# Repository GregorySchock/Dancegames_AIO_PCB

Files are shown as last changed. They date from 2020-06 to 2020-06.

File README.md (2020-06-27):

# Dancegames_AIO_PCB
PCB that can control all necessary aspects of hooking up a set of sensors to a PC in order to play games such as DDR and PIU

Made to have an arduino pro micro (or compatible) board inserted in the corner. Also has a set of buttons and LEDs to assist in calibration, if using velostat sensors that support automatic calibration routines. See my other repos for that code, if interested.

Designed in KiCad. A set of 5 boards is pretty cheap if purchased from a site like JLCPCB, just upload the GERBERS to their order form. For the rest of the components, see the BOM file for product numbers.

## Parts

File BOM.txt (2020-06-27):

If you'd like to do a 1:1 recreation of what I've made, these are the part numbers for the components I used. All parts were purchased on Mouser, with the exception of the pro micro and its PCB leg headers (both sourced via aliexpress).
I'll provide the manufacturer product numbers for each component, rather than the mouser number, should you prefer another vendor such as DigiKey or LCSC.
1 PCB (from JLC, using the board files here)
1 Potentiometer - PTV09A-4015F-B102
6 tactile switches - FSM6JH
1 10 hole terminal block - TB001-500-10BE
5 through hole resistors (I used 220 ohm but I'd recommend going higher, mine are almost blindingly bright)- CFR-25JT-52-220R
5 LEDs (Accidentally ordered oval ones, but just about any 5v LEDs will work just fine)- C4SMF-BJF-CR24Q4T2

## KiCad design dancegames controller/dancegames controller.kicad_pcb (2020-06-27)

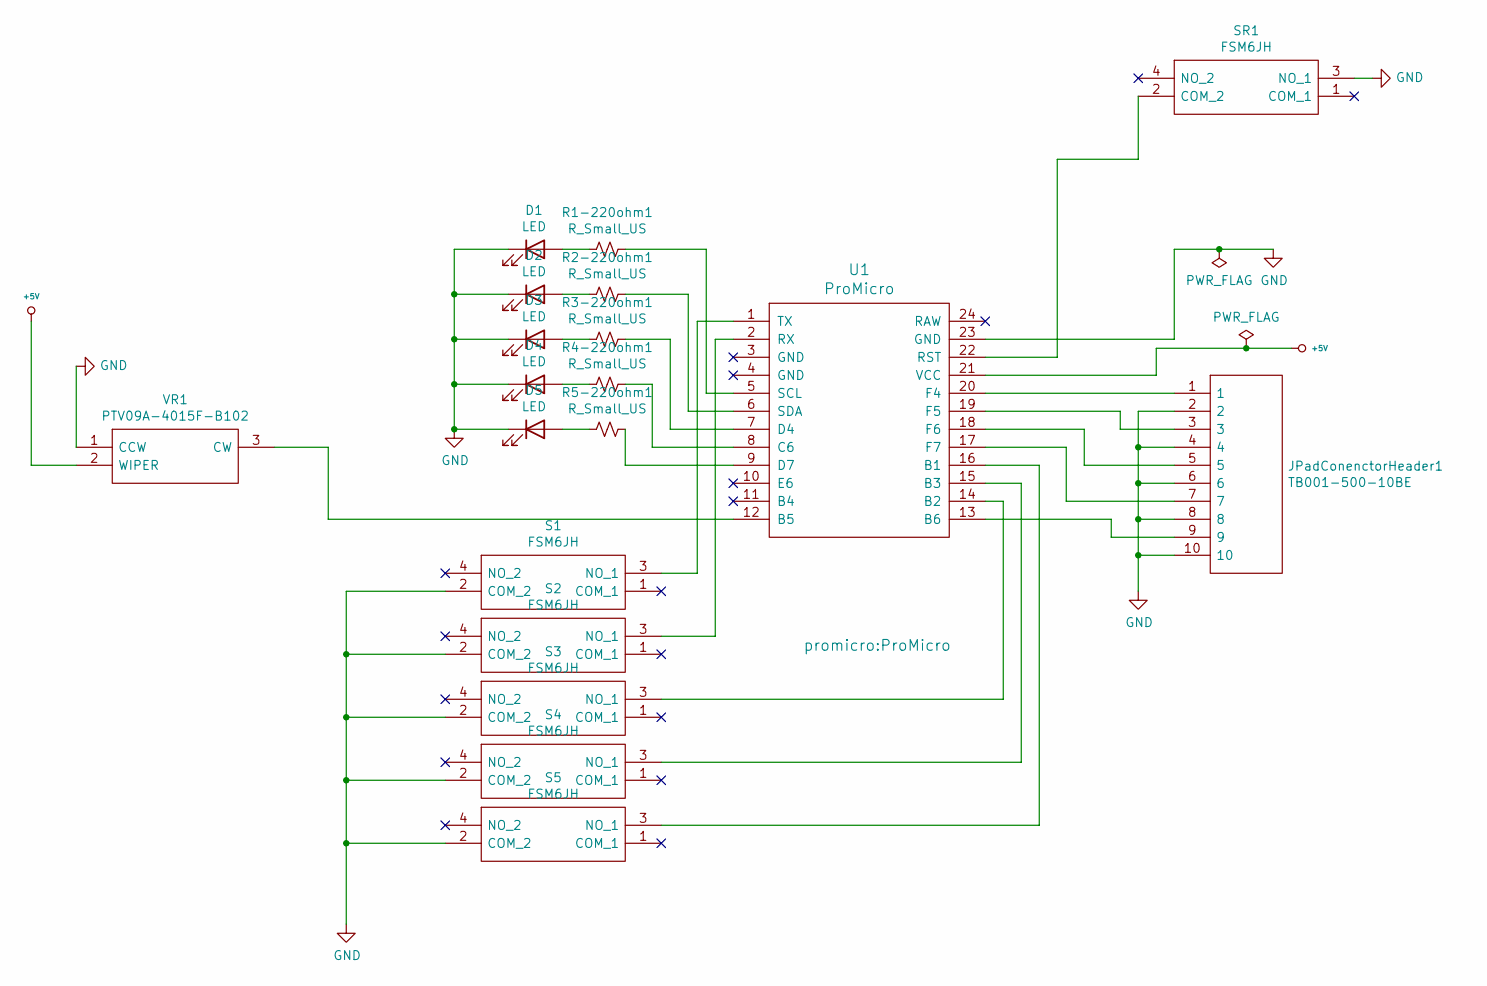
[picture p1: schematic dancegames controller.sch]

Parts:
D1, D2, D3, D4, D5: LED; LED_D4.0mm_1.25mmhole
JPadConenctorHeader1: TB001-500-10BE; SHDR10W100P0X500_1X10_5000X900X1250P; Mouser Part Number 490-TB001-500-10BE
R1-220ohm1, R2-220ohm1, R3-220ohm1, R4-220ohm1, R5-220ohm1: R_Small_US; R_Axial_DIN0207_L6.3mm_D2.5mm_P7.62mm_Horizontal
S1, S2, S3, S4, S5: FSM6JH; Mouser Part Number 506-FSM6JH
SR1: FSM6JH; Mouser Part Number 506-FSM6JH
U1: ProMicro
VR1: PTV09A-4015F-B102; PTV09A4020FB103; Mouser Part Number 652-PTV09A-4015FB102

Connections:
+5V: U1.21 (VCC), VR1.2 (WIPER)
GND: D1.1 (K), D2.1 (K), D3.1 (K), D4.1 (K), D5.1 (K), JPadConenctorHeader1.2, JPadConenctorHeader1.4, JPadConenctorHeader1.6, JPadConenctorHeader1.8, JPadConenctorHeader1.10, S1.2 (COM_2), S2.2 (COM_2), S3.2 (COM_2), S4.2 (COM_2), S5.2 (COM_2), SR1.3 (NO_1), U1.23 (GND), VR1.1 (CCW)
unnamed: D1.2 (A), R1-220ohm1.1
unnamed: D2.2 (A), R2-220ohm1.1
unnamed: D3.2 (A), R3-220ohm1.1
unnamed: D4.2 (A), R4-220ohm1.1
unnamed: D5.2 (A), R5-220ohm1.1
unnamed: JPadConenctorHeader1.1, U1.20 (F4)
unnamed: JPadConenctorHeader1.3, U1.19 (F5)
unnamed: JPadConenctorHeader1.5, U1.18 (F6)
unnamed: JPadConenctorHeader1.7, U1.17 (F7)
unnamed: JPadConenctorHeader1.9, U1.13 (B6)
unnamed: R1-220ohm1.2, U1.5 (SCL)
unnamed: R2-220ohm1.2, U1.6 (SDA)
unnamed: R3-220ohm1.2, U1.7 (D4)
unnamed: R4-220ohm1.2, U1.8 (C6)
unnamed: R5-220ohm1.2, U1.9 (D7)
unnamed: S1.3 (NO_1), U1.1 (TX)
unnamed: S2.3 (NO_1), U1.2 (RX)
unnamed: S3.3 (NO_1), U1.14 (B2)
unnamed: S4.3 (NO_1), U1.15 (B3)
unnamed: S5.3 (NO_1), U1.16 (B1)
unnamed: SR1.2 (COM_2), U1.22 (RST)
unnamed: U1.12 (B5), VR1.3 (CW)

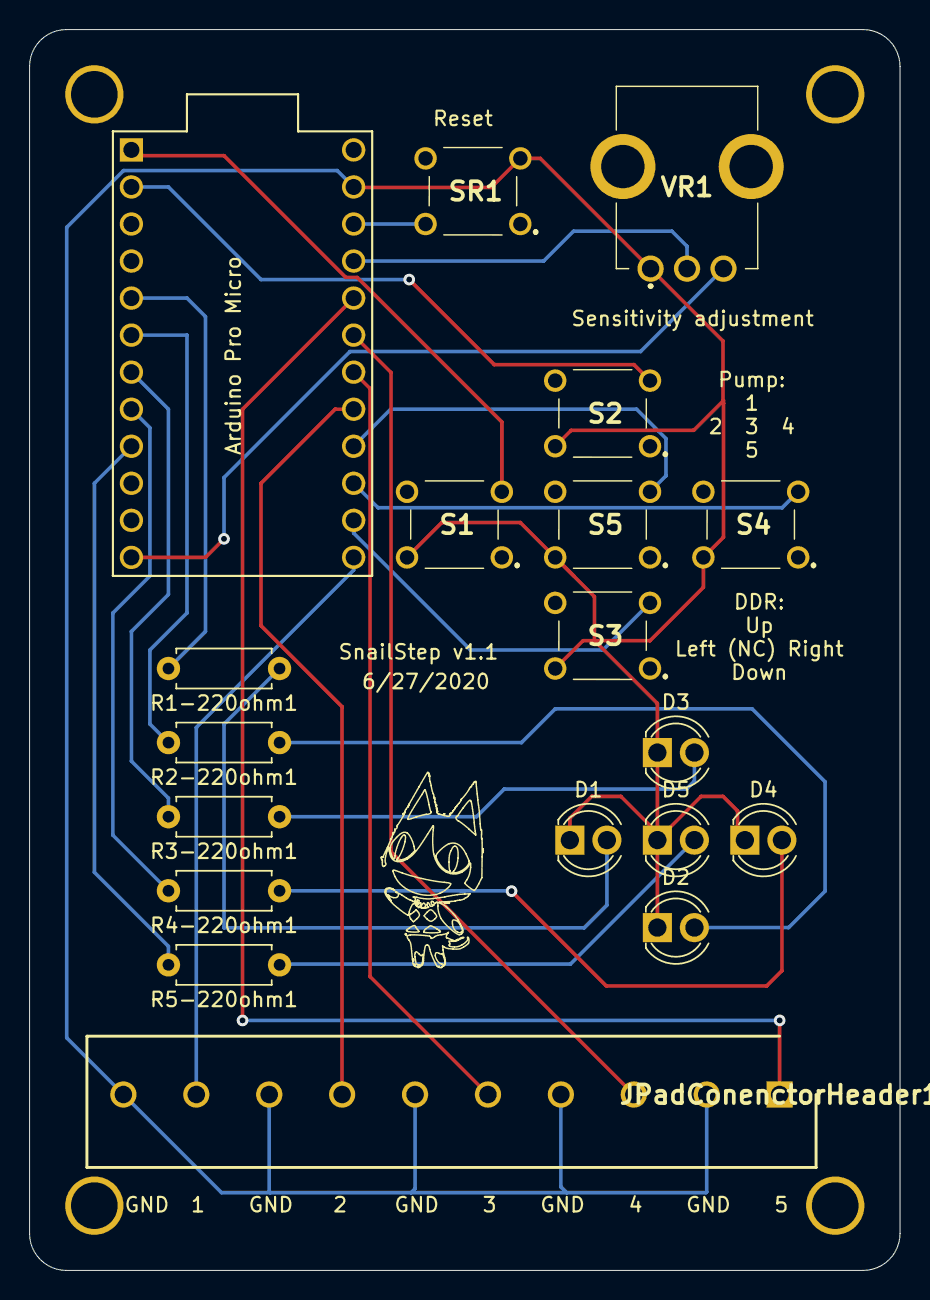
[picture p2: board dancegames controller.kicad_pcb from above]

Board: 2 copper layers, 59.7 x 85.1 mm, 23 parts (0 on the bottom side), 24 nets.

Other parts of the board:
HOLE_M3, HOLE_M3#2, HOLE_M3#3, HOLE_M3#4: VAL**; HOLE_M3
